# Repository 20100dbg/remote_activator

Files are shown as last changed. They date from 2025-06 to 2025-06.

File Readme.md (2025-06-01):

## Introduction
Control one or many remote switches using LoRa, from your smartphone.

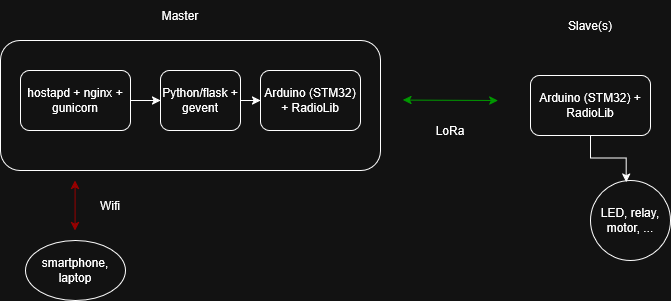
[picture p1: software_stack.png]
Software stack


## Repository content

This repo contains everything to build this project from scratch.

- lora-e5 contains code to re-program the Lora-e5-mini board for both master and slave
- master_web contains the backend code that is placed on the pi zero
- models contains Freecad files of cases for both master and slave

And this Readme file gives detailed instructions to setup LoRa-e5-mini boards and the complete backend stack on the pi zero.

## Hardware
The master is using a [pi zero 2 W](https://www.gotronic.fr/art-carte-raspberry-pi-zero-2-w-34463.htm) and a [LoRa-e5-mini](https://www.gotronic.fr/art-carte-wio-e5-mini-113990939-33674.htm). 

The pi zero is powered with an external battery

LiPo Amigo Pro https://www.gotronic.fr/art-chargeur-lipo-amigo-pro-pim612-38175.htm
Accu LiPo 1500 mAh https://www.gotronic.fr/art-accu-lipo-3-7-vcc-1500-mah-thym-bat-37198.htm

## Wiring

Master

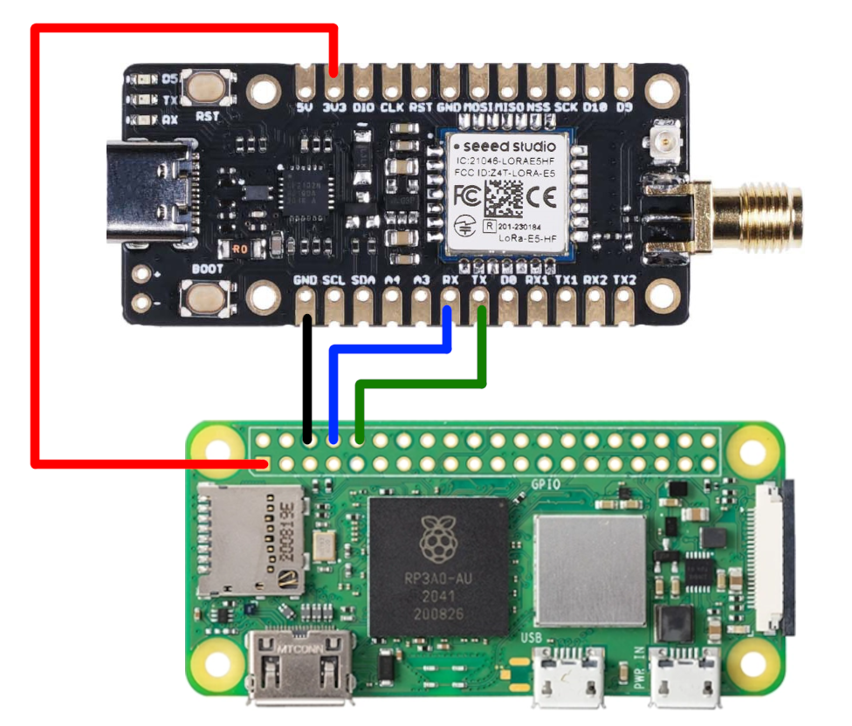
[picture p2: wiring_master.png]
Master wiring


Slave

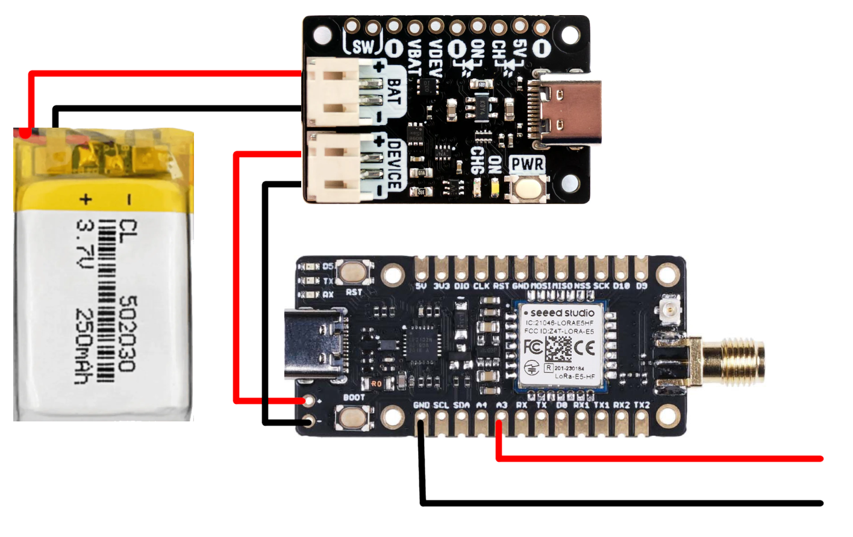
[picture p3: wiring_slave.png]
Slave wiring


## Program LoRa-e5-mini board

The code is in master and slave directories.
Follow this guide : https://github.com/20100dbg/LoRa

## Install flask stack on Rpi

mkdir remote_activator
cd remote_activator
python -m venv .venv
source .venv/bin/activate

#### Install packages
```
pip install pyserial flask flask-socketio gevent gunicorn
```

```
sudo apt update
sudo apt install nginx hostapd dnsmasq
```

#### DNS conf

Create `/etc/dnsmasq.d/090_wlan0.conf` with this content

```
interface=wlan0
dhcp-range=10.3.141.50,10.3.141.255,255.255.255.0,12h
dhcp-option=6,10.3.141.1
no-resolv
server=1.1.1.1
address=/remote_activator.com /10.3.141.1
```

#### Nginx conf

Edit `/etc/nginx/nginx.conf`, add **into** http section :

```
server {
    listen       80;
    listen       [::]:80;
    server_name  remote_activator.com;

    location / {
        include proxy_params;
        proxy_pass http://127.0.0.1:5000;
    }

    location /socket.io {
        proxy_pass http://127.0.0.1:5000/socket.io;
        proxy_redirect off;
        proxy_buffering off;
        proxy_set_header Host $host;
        proxy_set_header X-Real-IP $remote_addr;
        proxy_set_header X-Forwarded-For $proxy_add_x_forwarded_for;
        proxy_http_version 1.1;
        proxy_set_header Upgrade $http_upgrade;
        proxy_set_header Connection "Upgrade";
        proxy_hide_header Access-Control-Allow-Origin;
    }
}
```

#### Create gunicorn service

Create `/etc/systemd/system/gunicorn.service` with this content :

```
[Unit]
Description=gunicorn
After=network.target

[Service]
User=rpi
WorkingDirectory=/home/rpi/remote_activator/
ExecStart=/home/rpi/remote_activator/gunicorn.sh
Restart=always

[Install]
WantedBy=multi-user.target
```

#### Create wifiap service

Create `/etc/systemd/system/wifiap.service` with this content :

```
[Unit]
Description=wifiap
After=network.target

[Service]
User=rpi
WorkingDirectory=/home/rpi/remote_activator/
ExecStart=/home/rpi/remote_activator/wifiap.sh
Restart=always

[Install]
WantedBy=multi-user.target
```

#### Add entry in /etc/hosts

```
10.3.141.1 remote_activator.com
```

#### hostapd conf

Edit `/etc/hostapd/hostapd.conf` with this content :

```
interface=wlan0
driver=nl80211
ssid=remote_activator
hw_mode=g
channel=6
beacon_int=100
dtim_period=2
max_num_sta=255
rts_threshold=2347
fragm_threshold=2346

#auth_algs=0
wpa=2
wpa_passphrase=Azerty123+
wpa_key_mgmt=WPA-PSK
wpa_pairwise=CCMP
rsn_pairwise=CCMP
```

#### IP conf

Edit `/etc/network/interfaces.d/00-static` with this content :

```
auto wlan0
iface wlan0 inet static
address 10.3.141.1
netmask 255.255.255.0
netmask 255.255.255.0
```

#### Register services

```
sudo systemctl enable wifiap.service
sudo systemctl enable gunicorn.service
sudo systemctl daemon-reload
```

#### Reboot to finish

```
sudo reboot
```

## References

https://medium.com/@chandan-sharma/powering-flask-with-websockets-ca9f5a097ad9

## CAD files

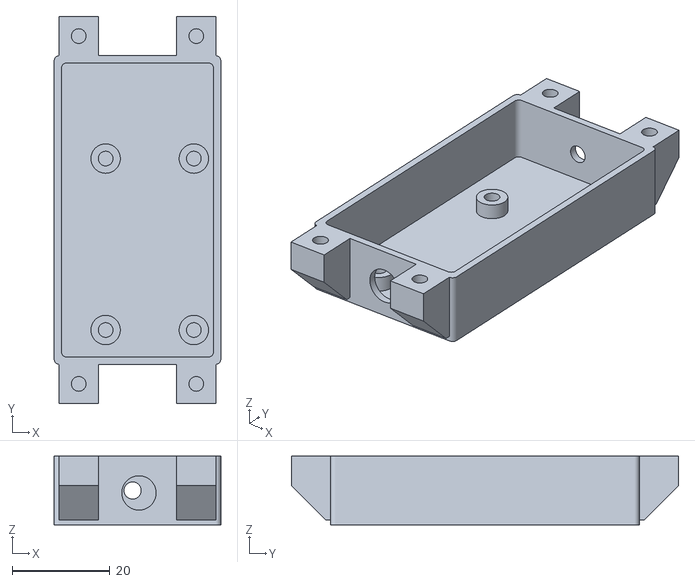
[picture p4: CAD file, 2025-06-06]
models/pydeto_slave-Corps bas.stl
34.0 x 79.0 x 14.0

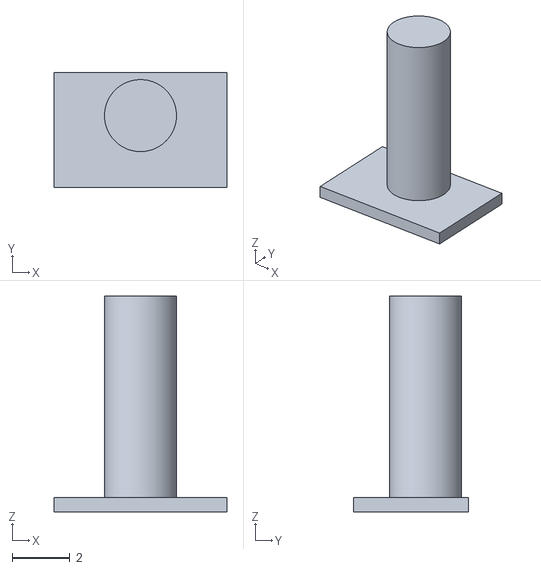
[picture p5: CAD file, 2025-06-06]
models/pydeto_slave-Corps teton.stl
6.00 x 4.00 x 7.50

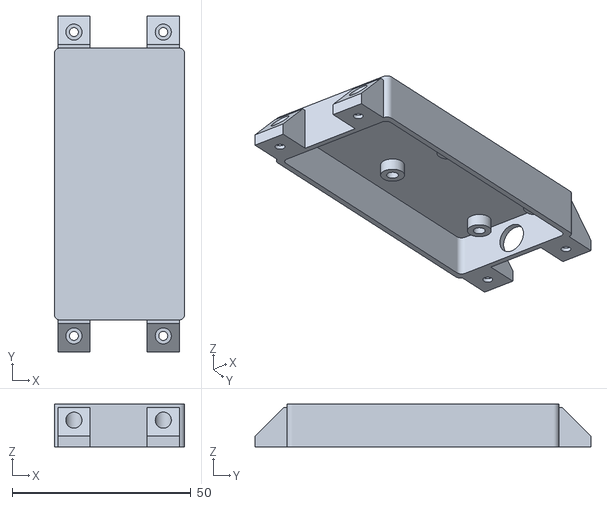
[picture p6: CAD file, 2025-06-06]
models/pydeto_master-Corps haut.stl
36.5 x 94.0 x 12.0

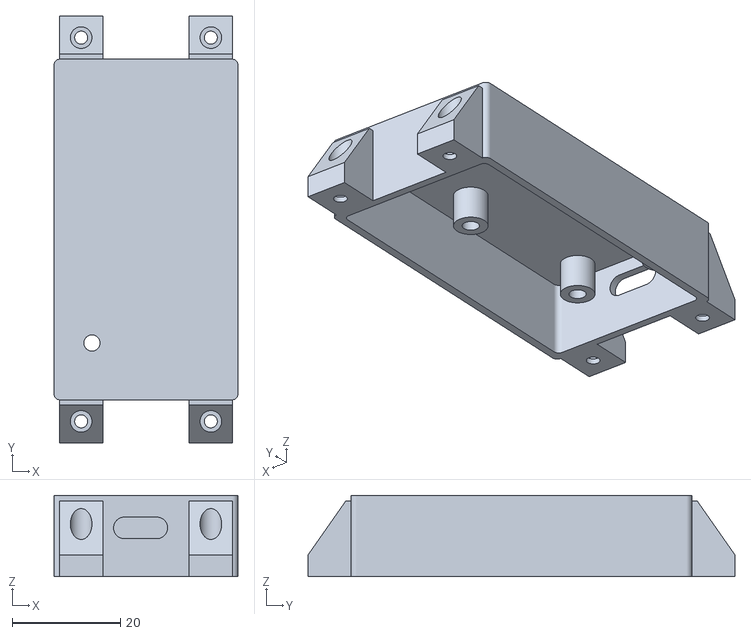
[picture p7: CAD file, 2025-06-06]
models/pydeto_slave-Corps haut.stl
34.0 x 79.0 x 15.0

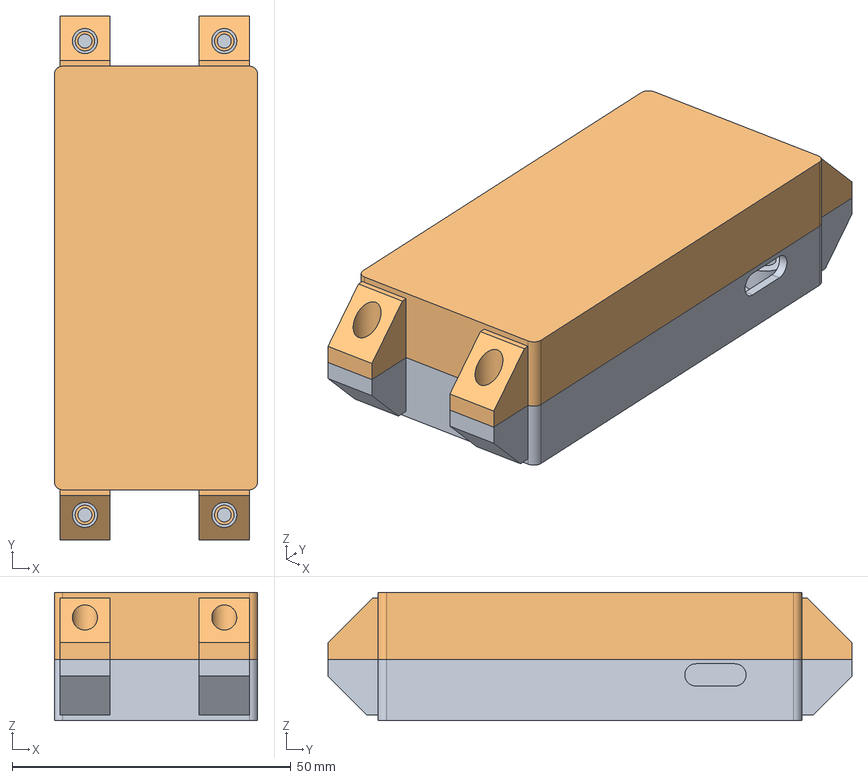
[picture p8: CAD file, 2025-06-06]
models/pydeto_master.FCStd
36.5 x 94.0 x 23.0 mm
Corps bas
Corps haut

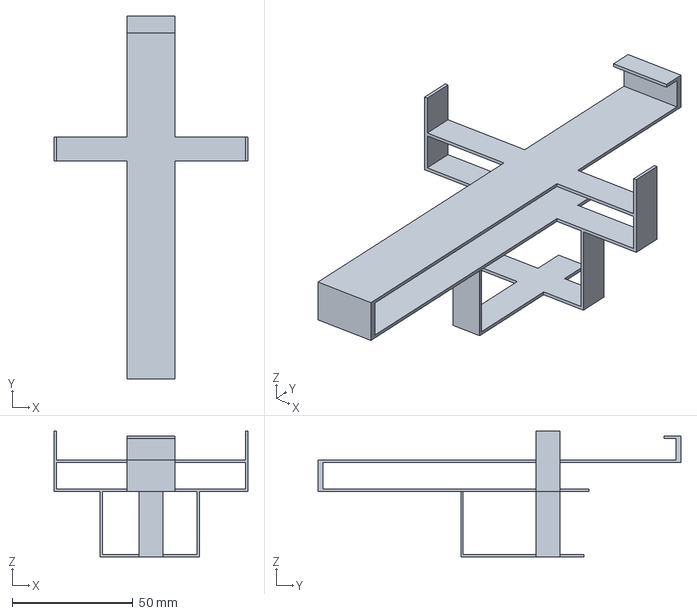
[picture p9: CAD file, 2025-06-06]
models/coque telephone.FCStd
80.0 x 150.0 x 52.0 mm

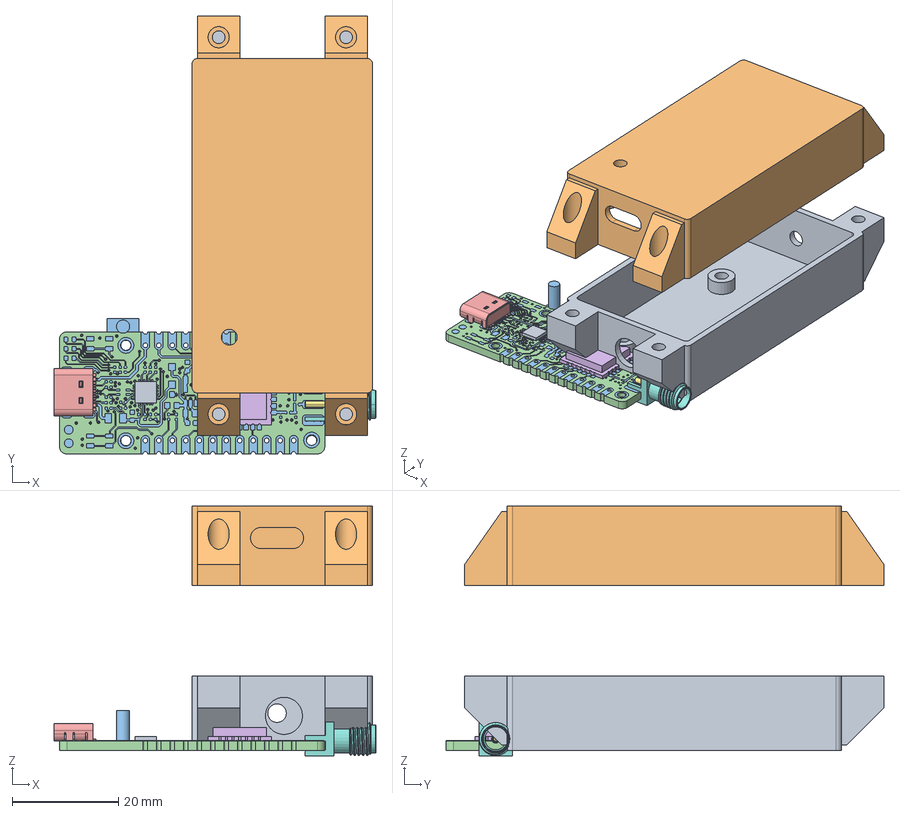
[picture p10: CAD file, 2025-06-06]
models/pydeto_slave.FCStd
60.6 x 82.5 x 47.1 mm
Corps bas
Corps haut
Corps teton
MainBoard
USB Type C Port (SMD Type)
LoRaSTM32Chip
E10_433M_SMA122
E10_433M_SMA123
CP2012
u.Fl Antenna Connector - 523-A-1JB
Top Traces

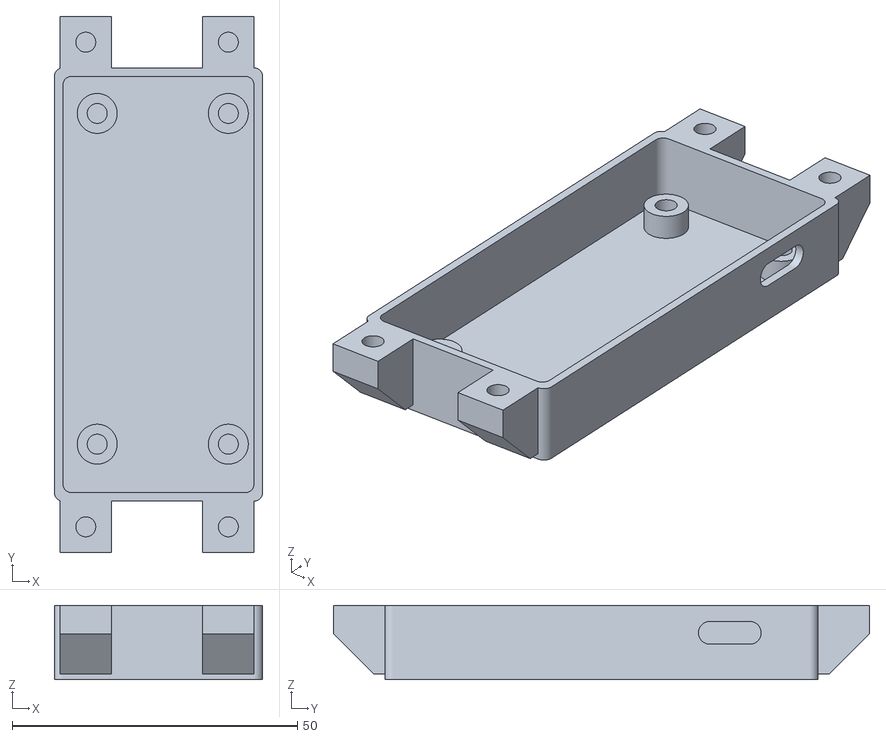
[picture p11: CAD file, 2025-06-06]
models/pydeto_master-Corps bas.stl
36.5 x 94.0 x 13.0

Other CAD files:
models/coque telephone-Corps.stl

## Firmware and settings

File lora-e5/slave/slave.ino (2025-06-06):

#include <RadioLib.h>

// no need to configure pins, signals are routed to the radio internally
STM32WLx radio = new STM32WLx_Module();

// set RF switch configuration for Nucleo WL55JC1
// NOTE: other boards may be different!
//       Some boards may not have either LP or HP.
//       For those, do not set the LP/HP entry in the table.
static const uint32_t rfswitch_pins[] = {PC_3,  PC_4,  PC_5, RADIOLIB_NC, RADIOLIB_NC};
static const Module::RfSwitchMode_t rfswitch_table[] = {
  {STM32WLx::MODE_IDLE,  {LOW,  LOW,  LOW}},
  {STM32WLx::MODE_RX,    {HIGH, HIGH, LOW}},
  {STM32WLx::MODE_TX_LP, {HIGH, HIGH, HIGH}},
  {STM32WLx::MODE_TX_HP, {HIGH, LOW,  HIGH}},
  END_OF_MODE_TABLE,
};

static const int max_size = 256;
byte serial_buffer[max_size];
static const int local_addr = 3;

#define MSG_PING 1
#define MSG_PING_ACK 2
#define MSG_FIRE 3
#define MSG_FIRE_ACK 4


volatile bool receivedFlag = false;
void setFlag(void) {
  receivedFlag = true;
}

// SYNC - TYPE - SIZE - DATA

void handle_packet(int type, int size, byte *payload) {

    for (int i = 0; i < size; i++) {

      int to = payload[i];
      if (to == local_addr || to == 255) {

        if (type == MSG_FIRE) {

          digitalWrite(PB3, HIGH);
          delay(400);
          digitalWrite(PB3, LOW);
        }
        else if (type == MSG_PING) {

          radio.clearDio1Action();
          byte send_buffer[] = {0xb5, 0x62, MSG_PING_ACK, 1, local_addr};
          radio.transmit(send_buffer, 5);
          
          radio.setDio1Action(setFlag);
          radio.startReceive();
        }

      } //end to == local_addr

    }  //end for

}

void read_received(byte *buffer, int count) {

  for (int i = 0; i < count - 1; i++) {

    if (buffer[i] == 0xb5 && buffer[i + 1] == 0x62) {

      int type = buffer[i+2];
      int size = buffer[i+3];

      handle_packet(type, size, &buffer[i+4]);
    }
  }
    

}


void setup() {
  Serial.begin(115200);
  Serial.setTimeout(100);

  pinMode(PB3, OUTPUT);

  // set RF switch control configuration
  // this has to be done prior to calling begin()
  radio.setRfSwitchTable(rfswitch_pins, rfswitch_table);


  float freq = 495.5; //150-960mhz
  float bw = 250.0; //125,250,500
  uint8_t sf = 10; //7,8,9,10,11,12
  uint8_t cr = 6; //5,6,7,8
  uint8_t syncWord = RADIOLIB_SX126X_SYNC_WORD_PRIVATE;
  int8_t power = 22; //22, 17, 14, 10
  uint16_t preambleLength = 8;


  int state = radio.begin(freq, bw, sf, cr, syncWord, power, preambleLength);
  // set appropriate TCXO voltage for Nucleo WL55JC1
  //state = radio.setTCXO(1.7);

  radio.setDio1Action(setFlag);
  radio.startReceive();
  Serial.print("ready");
}


void loop() {

  if(receivedFlag) {
    receivedFlag = false;
    int count = radio.getPacketLength(true);

    if (count > 0) {
      byte received_buffer[count];
      int state = radio.readData(received_buffer, count);

      //Serial.write(received_buffer, count);

      if (state == RADIOLIB_ERR_NONE) {
        read_received(received_buffer, count);
      }
    }
  }

}

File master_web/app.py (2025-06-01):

import gevent
import threading
import time
from lora import lora
from flask import Flask, request, make_response
from flask_socketio import SocketIO, emit
from enum import Enum

class MsgType(Enum):
    PING = 1
    PING_ACK = 2
    FIRE = 3
    FIRE_ACK = 4


#sync - type - size - payload

sync_word = b"\xB5\x62"

app = Flask(__name__)
socketio = SocketIO(app, cors_allowed_origins='*',async_mode='gevent')

@app.route("/")
def main():
    tpl = open('templates/main.html', 'r').read()
    #tpl = tpl.replace('{{nb_ied}}', str(nb_ied))

    response = make_response(tpl)
    response.headers["Cache-Control"] = "no-cache, no-store, must-revalidate"
    return response


@socketio.on('fire')
def fire(params):

    if len(params['id']) > 0:
        tab_ied = [int(id_ied) for id_ied in params['id']]

        for x in range(2):
            lora.send_bytes(build_message(MsgType.FIRE.value, bytes(tab_ied)))
            time.sleep(0.1)



@socketio.on('ping')
def ping(params):

    global ping_time
    ping_time = int(params['time'])

    if len(params['id']) > 0:
        tab_ied = [int(id_ied) for id_ied in params['id']]        
        lora.send_bytes(build_message(MsgType.PING.value, bytes(tab_ied)))


@socketio.on('update')
def update():
    socketio.emit('update', dict_ied)



##########
#
# LoRa
#
##########

def find_sync(data, idx_start=0):
    for idx in range(idx_start, len(data)):
        if data[idx:idx+len(sync_word)] == sync_word:
            return idx

    return -1


def listen_loop(callback):
    """ Check if data is received """
    
    buffer_receive = b''
    last_receive = 0
    
    while True:
        data = lora.receive()

        if data:
            buffer_receive += data
            last_receive = time.time()

        while True:
            idx_start = find_sync(buffer_receive)

            if idx_start >= 0:
                buffer_receive = buffer_receive[idx_start:]

                idx_end = find_sync(buffer_receive, idx_start=2)
                
                if idx_end == -1:
                    idx_end = len(buffer_receive)

                packet = buffer_receive[idx_start:idx_end]

                callback(packet)
                buffer_receive = buffer_receive[idx_end:]                        
            else:
                break


        #time.sleep(0.05) #minimal sleep time
        time.sleep(0.1)



def callback_lora(data):
    """ Handles every message received from LoRa """

    msg_type = data[2]
    msg_size = data[3]
    msg_from = data[4]

    if msg_type == MsgType.PING_ACK.value:
        
        if msg_from not in dict_ied:
            add_ied(msg_from)
        
        if ping_time > dict_ied[msg_from][1]:
            dict_ied[msg_from][1] = ping_time

        dict_ied[msg_from][2] = dict_ied[msg_from][1]

    update()


def build_message(type, data):

    size = len(data)
    packet = sync_word
    packet += type.to_bytes(1, 'big')
    packet += size.to_bytes(1, 'big')
    packet += data
    return packet




##########
#
# xxx
#
##########


def add_ied(id_ied):
    dict_ied[id_ied] = ["IED " + str(id_ied), ping_time, ping_time]


def bytes_to_hex(arr):
    return ' '.join(['{:02X}'.format(b) for b in arr])

dict_ied = {}
nb_ied = 3

global ping_time
ping_time = 0

for x in range(1,nb_ied+1):
    add_ied(x)


lora = lora(port="/dev/ttyS0")

t_receive = threading.Thread(target=listen_loop, args=[callback_lora])
t_receive.start()

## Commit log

2024-10-22 ajouts des scripts démarrage, multiples corrections
    [app.py]
2025-06-06 update code and models
    [coque telephone-Corps.stl, coque telephone.FCStd, pydeto_master-Corps bas.stl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]
